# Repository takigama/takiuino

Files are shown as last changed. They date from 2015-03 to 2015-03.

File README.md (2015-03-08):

# Takiuino - the arduino compatible board for ME!

Just a WIP atm, look in the eagle directory and you can see the boards and their OSHPark links, though v2.0 has now
been tested against both arduino v1.0.x and arduino v1.5.7 and v1.6.0.

The main site for the takiuino is here: http://pjr.cc/tu/ (which is comming soon)

## Thanks go to....

Maniacbug - for his work on the 1284 originally, from [here](https://maniacbug.wordpress.com/2011/11/27/arduino-on-atmega1284p-4/).

The Optiboot folk - for making the awesome optiboot code! Available [here](https://code.google.com/p/optiboot/).

## What is it?

A fork of Maniacbug's mighty1284 code base, also includes the 644p code.

I've removed everything except the optiboot options (for now)

## What do you need?

First you need the board, which is on oshpark [here](https://oshpark.com/shared_projects/BunCIt50) for V3.1 or
[here](https://oshpark.com/shared_projects/wfCfnxof) for V3.2. The only difference between them is how the ICSP and reset swtiches are layed out.

# V3.1
Top
Bottom

# V3.2
Top
Bottom
Then you need to make the board (its pretty simple)

1. decide what you need, if your powering from a stable 5v source, you dont need the 5v REG (though keeping the 5v cap, C1, isnt a bad idea)
If you dont need a 3.3v line, you can drop the 3.3v REG as well (and its capacitor, C2).

2. the polarized components (2 caps, 2 leds) have their positive lines marked

3. Conquer the world. They'll be a better written tutorial coming soon, as well as an annotated
image of the actual board and components that go on it. But for the impatient the components are as follows:

- C1, C2: 10uf Tant CAP (16v rated)
- RES: SMD resontator (16mhz), Murata CSTCE16M0V53-R0 is appropriate
- C4: 0.1uf (100nf) 0603 sized ceramic cap
- R1: 330 ohm 0603 sized resister
- R2: 220 ohm 0603 sized resister (can also be 330 ohm if you wish)
- S1: SMD push button switch
- L2, L3: 0603 sized SMD led (note polarity)
- 1117-5v: AMS/LM1117 5v regulator
- 1117-3.3v: AMS/LM1117 3.3v regulator
- ATmega: ATmega1284p-au or ATmega644p-au (which ever suits you) should be a little circle on the chip, which 
goes with the printed circle on the board

Personally i find the resonator the hardest bit to solder, but doesnt take too much to long to get the hang
of it. After that, hook up an ASP and go program it directly with code, or use a bootloader and program via
the serial pinouts (note you'll need a USB to uart thingo).

If it all works, L3 should come on when power to the board is applied and you can control L2 via pummelling
pin 23 (which is what L2 is connected to). The following code should work:

```
int ledPin = 23;                 // LED connected to digital pin 23
float tLat = 1024;
bool dirUp = true;

void setup()
{
  Serial.begin(115200);
  pinMode(ledPin, OUTPUT);      // sets the digital pin as output
}

void loop()
{

  digitalWrite(ledPin, HIGH);   // sets the LED on
  delay(tLat);                  // waits for a bit
  digitalWrite(LED, LOW);       // sets the LED off
  // note that i use "LED" above, which is defined
  // in the hardware library for this pin
  delay(tLat);                  // waits for a bit

  if(tLat > 1024) {
    Serial.println("Switch direction, down");
    dirUp = false;

  }

  if(tLat < 2) {
    Serial.println("Switch direction, up");
    dirUp = true;
  }

  if(dirUp) {
    tLat = tLat*1.2;
  } else {
    tLat = tLat/1.2;
  }

  Serial.print("tlat now: ");
  Serial.println(tLat);

}

```
This should cause the L2 led to start as a slow on/off then ramp up and eventually stay on, then reset and start again.

## Installation

copy the contents of the arduino-ide folder into you arduino ide's hardware directory

## Why?

Originally started as a project to create something very specific, hence why the original V1 board has a
MOSFET on the board.

Second reason was cause I could, always wanted to design my own board for a microctronoller and this worked
out well.

Third was that I wanted a board with more useful pinout info, not many of the smaller boards have any markings
to tell you which channel is a pwm line, etc. The code also allow you to call pins via the names on
either side of the board (hence whey they're both there).

Lastly, I needed something small (round the pro mini/micro size) with two serial ports, the ability to run
an OLED screen (which requires quite some memory) along with some other memory sapping parts

## TODO

- I think I may regret the position of the reset switch as its sitting very close to the resonator (i'll know once
the v3 prints arrive from OSH Park)
- Write a test harness and some programs to check that the pins all work

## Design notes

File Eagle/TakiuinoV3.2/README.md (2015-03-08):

# Takuino V3.2 - the final countdown, part 2

Flipped the ICSP header around, moved reset switch as it was a bit close to the resonator

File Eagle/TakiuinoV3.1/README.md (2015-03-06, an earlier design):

# Takuino V3.1 - the final countdown

Not quite here yet cause im a bit lazy sometimes.

Basically takiuino V3 will be V2 with the following additinos:
- silk screens on both sides with pin layouts
- ISCP Header holes
- Reset Button pads

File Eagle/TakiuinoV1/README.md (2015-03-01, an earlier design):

# Takiuino V1

This board had a very specific purpose and should never actually be built, unless you very much want a board with an inbuilt MOSFET connector.

I've included the gerber files, or alternatively it can be printed on oshpark https://oshpark.com/shared_projects/UIUpYUVF

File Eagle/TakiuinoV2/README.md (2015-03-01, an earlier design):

# Takuino V2

After making Takiuino V1, someone saw it and asked if they could have a generic version of it with all the pins exposed and without the mosfet driver. So here it is.

Also available on OSHPark: https://oshpark.com/shared_projects/RhMgGB3u

This board works quite well, though V3 which is just around the corner will be a bit of an improvement and best to hold off for that if you can

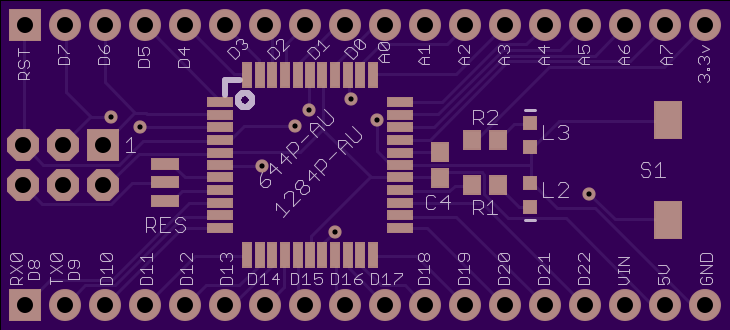
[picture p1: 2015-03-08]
Eagle/TakiuinoV3.2/oshpark-renders/top.png

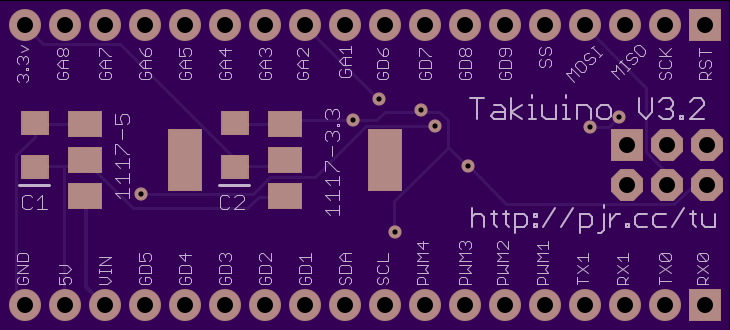
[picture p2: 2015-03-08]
Eagle/TakiuinoV3.2/oshpark-renders/bottom.png

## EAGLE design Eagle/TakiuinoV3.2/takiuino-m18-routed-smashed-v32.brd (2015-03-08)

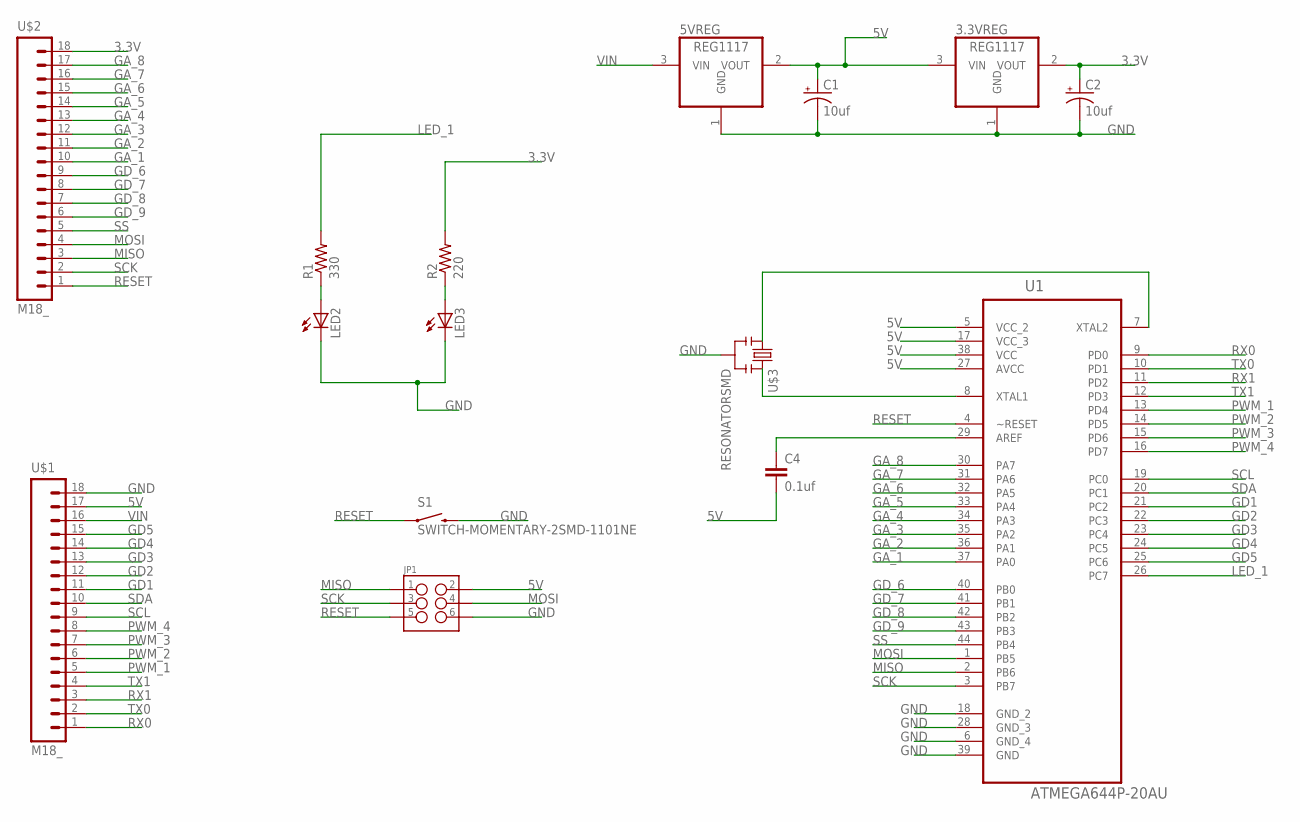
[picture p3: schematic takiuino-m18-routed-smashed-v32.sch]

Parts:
3.3VREG, 5VREG: REG1117; SOT223
C1, C2: 10uf; EIA3216
C4: 0.1uf; 0603-CAP
JP1: M03X2NO_SILK; 2X3-NS
LED2, LED3: LEDCHIP-LED0603; CHIP-LED0603
R1: 330; R0603
R2: 220; R0603
S1: SWITCH-MOMENTARY-2SMD-1101NE; TACTILE-SWITCH-1101NE
U1: ATMEGA644P-20AU; QFP80P1200X1200X120-44N
U$1, U$2: M18_; 1X18
U$3: RESONATORSMD; RESONATOR-SMD

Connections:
3.3V: 3.3VREG.2 (VOUT), C2.A (+), R2.2, U$2.18
5V: 3.3VREG.3 (VIN), 5VREG.2 (VOUT), C1.A (+), C4.2, JP1.2, U1.5 (VCC_2), U1.17 (VCC_3), U1.27 (AVCC), U1.38 (VCC), U$1.17
GA_1: U1.37 (PA0), U$2.10
GA_2: U1.36 (PA1), U$2.11
GA_3: U1.35 (PA2), U$2.12
GA_4: U1.34 (PA3), U$2.13
GA_5: U1.33 (PA4), U$2.14
GA_6: U1.32 (PA5), U$2.15
GA_7: U1.31 (PA6), U$2.16
GA_8: U1.30 (PA7), U$2.17
GD1: U1.21 (PC2), U$1.11
GD2: U1.22 (PC3), U$1.12
GD3: U1.23 (PC4), U$1.13
GD4: U1.24 (PC5), U$1.14
GD5: U1.25 (PC6), U$1.15
GD_6: U1.40 (PB0), U$2.9
GD_7: U1.41 (PB1), U$2.8
GD_8: U1.42 (PB2), U$2.7
GD_9: U1.43 (PB3), U$2.6
GND: 3.3VREG.1 (GND), 5VREG.1 (GND), C1.C (-), C2.C (-), JP1.6, LED2.C, LED3.C, S1.2, U1.6 (GND_4), U1.18 (GND_2), U1.28 (GND_3), U1.39 (GND), U$1.18, U$3.2
LED_1: R1.2, U1.26 (PC7)
MISO: JP1.1, U1.2 (PB6), U$2.3
MOSI: JP1.4, U1.1 (PB5), U$2.4
unnamed: U1.8 (XTAL1), U$3.3
unnamed: U1.7 (XTAL2), U$3.1
unnamed: C4.1, U1.29 (AREF)
unnamed: LED2.A, R1.1
unnamed: LED3.A, R2.1
PWM_1: U1.13 (PD4), U$1.5
PWM_2: U1.14 (PD5), U$1.6
PWM_3: U1.15 (PD6), U$1.7
PWM_4: U1.16 (PD7), U$1.8
RESET: JP1.5, S1.1, U1.4 (~RESET), U$2.1
RX0: U1.9 (PD0), U$1.1
RX1: U1.11 (PD2), U$1.3
SCK: JP1.3, U1.3 (PB7), U$2.2
SCL: U1.19 (PC0), U$1.9
SDA: U1.20 (PC1), U$1.10
SS: U1.44 (PB4), U$2.5
TX0: U1.10 (PD1), U$1.2
TX1: U1.12 (PD3), U$1.4
VIN: 5VREG.3 (VIN), U$1.16

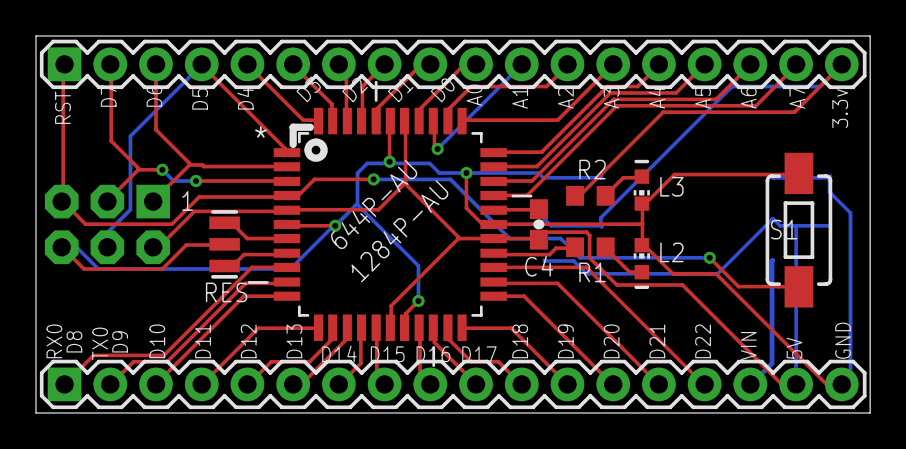
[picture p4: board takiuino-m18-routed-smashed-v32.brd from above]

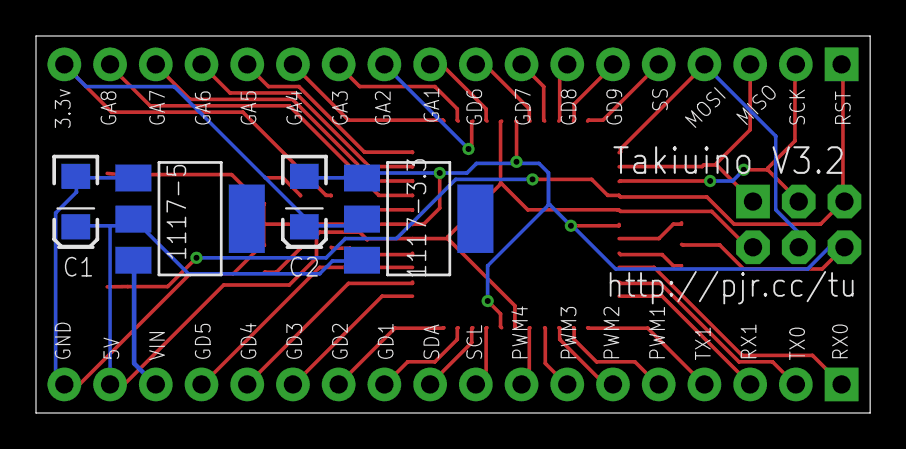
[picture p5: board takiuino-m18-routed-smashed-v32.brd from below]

Board: 2 copper layers, 46.3 x 20.9 mm, 15 parts (4 on the bottom side), 42 nets.

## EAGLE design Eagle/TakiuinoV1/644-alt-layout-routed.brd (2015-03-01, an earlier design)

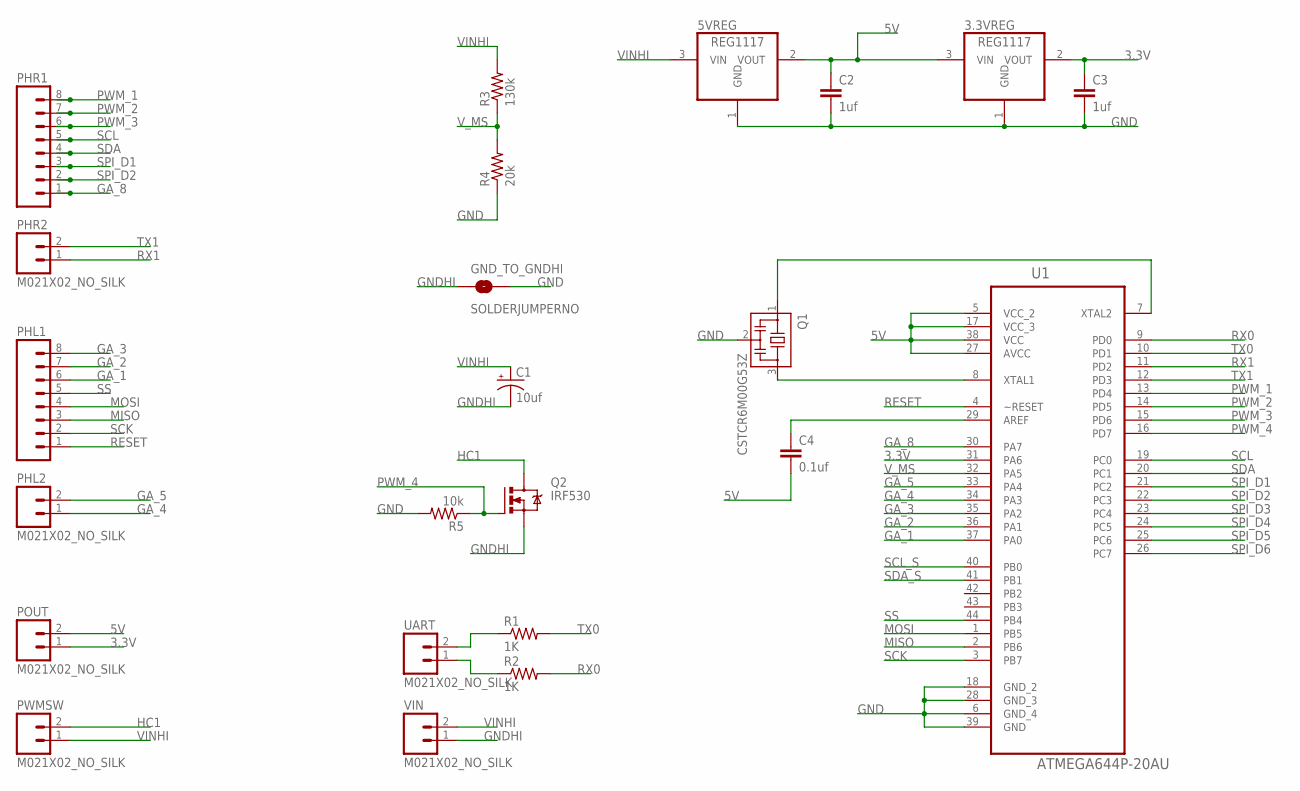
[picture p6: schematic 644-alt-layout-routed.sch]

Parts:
3.3VREG, 5VREG: REG1117; SOT223
C1: 10uf; EIA3216
C2, C3: 1uf; 0603-CAP
C4: 0.1uf; 0603-CAP
GND_TO_GNDHI: SOLDERJUMPERNO; SJ_2S-NO
PHL1: M08NO_SILK; 1X08_PIN1_NO_SILK
PHL2: M021X02_NO_SILK; 1X02_NO_SILK
PHR1: M08NO_SILK; 1X08_PIN1_NO_SILK
PHR2: M021X02_NO_SILK; 1X02_NO_SILK
POUT: M021X02_NO_SILK; 1X02_NO_SILK
PWMSW: M021X02_NO_SILK; 1X02_NO_SILK
Q1: CSTCR6M00G53Z; CSTCR6M
Q2: IRF530; TO220BV
R1, R2: 1K; 0603-RES
R3: 130k; 0603-RES
R4: 20k; 0603-RES
R5: 10k; 0603-RES
U1: ATMEGA644P-20AU; QFP80P1200X1200X120-44N
UART: M021X02_NO_SILK; 1X02_NO_SILK
VIN: M021X02_NO_SILK; 1X02_NO_SILK

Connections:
3.3V: 3.3VREG.2 (VOUT), C3.1, POUT.1, U1.31 (PA6)
5V: 3.3VREG.3 (VIN), 5VREG.2 (VOUT), C2.1, C4.2, POUT.2, U1.5 (VCC_2), U1.17 (VCC_3), U1.27 (AVCC), U1.38 (VCC)
GA_1: PHL1.6, U1.37 (PA0)
GA_2: PHL1.7, U1.36 (PA1)
GA_3: PHL1.8, U1.35 (PA2)
GA_4: PHL2.1, U1.34 (PA3)
GA_5: PHL2.2, U1.33 (PA4)
GA_8: PHR1.1, U1.30 (PA7)
GND: 3.3VREG.1 (GND), 5VREG.1 (GND), C2.2, C3.2, GND_TO_GNDHI.2, Q1.2, R4.1, R5.2, U1.6 (GND_4), U1.18 (GND_2), U1.28 (GND_3), U1.39 (GND)
GNDHI: C1.C (-), GND_TO_GNDHI.1, Q2.S, VIN.1
HC1: PWMSW.2, Q2.D
MISO: PHL1.3, U1.2 (PB6)
MOSI: PHL1.4, U1.1 (PB5)
unnamed: Q1.3, U1.8 (XTAL1)
unnamed: Q1.1, U1.7 (XTAL2)
unnamed: C4.1, U1.29 (AREF)
unnamed: R1.1, UART.2
unnamed: R2.1, UART.1
PWM_1: PHR1.8, U1.13 (PD4)
PWM_2: PHR1.7, U1.14 (PD5)
PWM_3: PHR1.6, U1.15 (PD6)
PWM_4: Q2.G, R5.1, U1.16 (PD7)
RESET: PHL1.1, U1.4 (~RESET)
RX0: R2.2, U1.9 (PD0)
RX1: PHR2.1, U1.11 (PD2)
SCK: PHL1.2, U1.3 (PB7)
SCL: PHR1.5, U1.19 (PC0)
SCL_S: U1.40 (PB0)
SDA: PHR1.4, U1.20 (PC1)
SDA_S: U1.41 (PB1)
SPI_D1: PHR1.3, U1.21 (PC2)
SPI_D2: PHR1.2, U1.22 (PC3)
SPI_D3: U1.23 (PC4)
SPI_D4: U1.24 (PC5)
SPI_D5: U1.25 (PC6)
SPI_D6: U1.26 (PC7)
SS: PHL1.5, U1.44 (PB4)
TX0: R1.2, U1.10 (PD1)
TX1: PHR2.2, U1.12 (PD3)
VINHI: 5VREG.3 (VIN), C1.A (+), PWMSW.1, R3.2, VIN.2
V_MS: R3.1, R4.2, U1.32 (PA5)

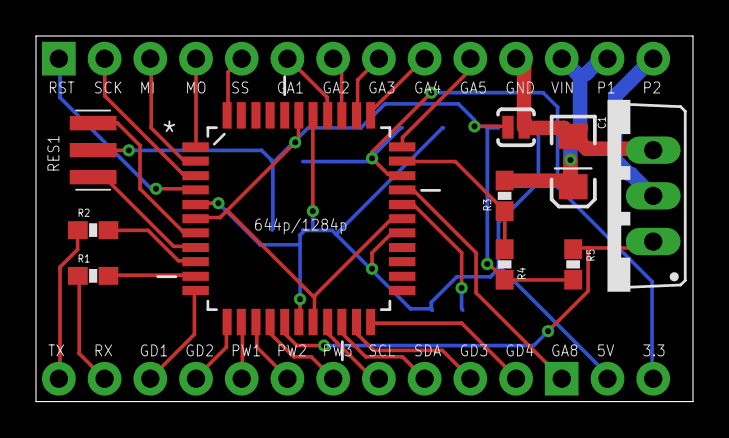
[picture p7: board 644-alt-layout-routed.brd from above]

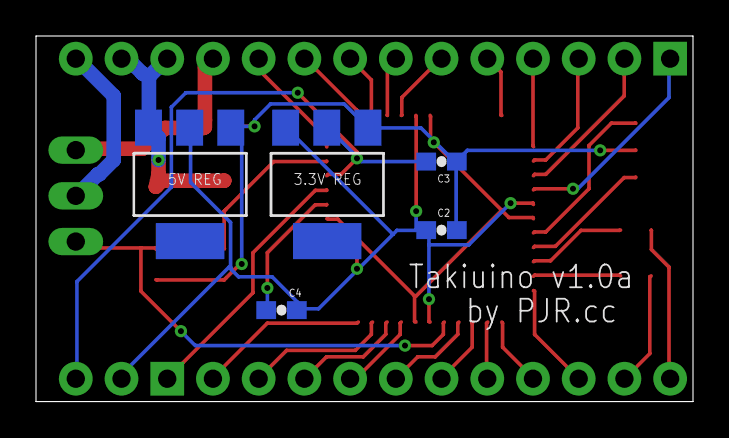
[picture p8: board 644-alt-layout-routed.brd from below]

Board: 2 copper layers, 36.5 x 20.3 mm, 23 parts (5 on the bottom side), 35 nets.

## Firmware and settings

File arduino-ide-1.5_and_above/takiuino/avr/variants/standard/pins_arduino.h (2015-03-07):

#ifndef Pins_Arduino_h
#define Pins_Arduino_h

#include <avr/pgmspace.h>

// ATMEL ATMEGA1284P
//
//                   +---\/---+
//           (D 0) PB0  1|        |40  PA0 (AI 0 / D24)
//           (D 1) PB1  2|        |39  PA1 (AI 1 / D25)
//      INT2 (D 2) PB2  3|        |38  PA2 (AI 2 / D26)
//       PWM (D 3) PB3  4|        |37  PA3 (AI 3 / D27)
//    PWM/SS (D 4) PB4  5|        |36  PA4 (AI 4 / D28)
//      MOSI (D 5) PB5  6|        |35  PA5 (AI 5 / D29)
//  PWM/MISO (D 6) PB6  7|        |34  PA6 (AI 6 / D30)
//   PWM/SCK (D 7) PB7  8|        |33  PA7 (AI 7 / D31)
//                 RST  9|        |32  AREF
//                 VCC 10|        |31  GND 
//                 GND 11|        |30  AVCC
//               XTAL2 12|        |29  PC7 (D 23)
//               XTAL1 13|        |28  PC6 (D 22)
//      RX0 (D 8)  PD0 14|        |27  PC5 (D 21) TDI
//      TX0 (D 9)  PD1 15|        |26  PC4 (D 20) TDO
// RX1/INT0 (D 10) PD2 16|        |25  PC3 (D 19) TMS
// TX1/INT1 (D 11) PD3 17|        |24  PC2 (D 18) TCK
//      PWM (D 12) PD4 18|        |23  PC1 (D 17) SDA
//      PWM (D 13) PD5 19|        |22  PC0 (D 16) SCL
//      PWM (D 14) PD6 20|        |21  PD7 (D 15) PWM
//                   +--------+
//

/*
   PCINT15-8: D7-0  : bit 1
   PCINT31-24: D15-8  : bit 3
   PCINT23-16: D23-16 : bit 2
   PCINT7-0: D31-24   : bit 0
   */

#define NUM_DIGITAL_PINS            31
#define NUM_ANALOG_INPUTS           8
#define analogInputToDigitalPin(p)  ((p < NUM_ANALOG_INPUTS) ? (p) + 24 : -1)

#define digitalPinHasPWM(p)         ((p) == 3 || (p) == 4 || (p) == 6 || (p) == 7 || (p) == 12 || (p) == 13 || (p) == 14 || (p) == 15)


// backside pin def's
static const uint8_t PWM1 = 12;
static const uint8_t PWM2 = 13;
static const uint8_t PWM3 = 14;
static const uint8_t PWM4 = 15;

// second serial port
static const uint8_t RX1 = 10;
static const uint8_t TX1 = 11;

// on board led which i didnt bring to a pin
static const uint8_t LED = 23;
static const uint8_t LED1 = 23;

// general analog ports
static const uint8_t GA1 = 24;
static const uint8_t GA2 = 25;
static const uint8_t GA3 = 26;
static const uint8_t GA4 = 27;
static const uint8_t GA5 = 28;
static const uint8_t GA6 = 29;
static const uint8_t GA7 = 30;
static const uint8_t GA8 = 31;

// general digital ports
static const uint8_t GD1 = 18;
static const uint8_t GD2 = 19;
static const uint8_t GD3 = 20;
static const uint8_t GD4 = 21;
static const uint8_t GD5 = 22;
static const uint8_t GD6 = 0;
static const uint8_t GD7 = 1;
static const uint8_t GD8 = 2;
static const uint8_t GD9 = 3;

// end backside pin defs


static const uint8_t SS   = 4;
static const uint8_t MOSI = 5;
static const uint8_t MISO = 6;
static const uint8_t SCK  = 7;

static const uint8_t SDA = 17;
static const uint8_t SCL = 16;

static const uint8_t A0 = 24;
static const uint8_t A1 = 25;
static const uint8_t A2 = 26;
static const uint8_t A3 = 27;
static const uint8_t A4 = 28;
static const uint8_t A5 = 29;
static const uint8_t A6 = 30;
static const uint8_t A7 = 31;

#define digitalPinToPCICR(p)    (((p) >= 0 && (p) < NUM_DIGITAL_PINS) ? (&PCICR) : ((uint8_t *)0))
#define digitalPinToPCICRbit(p) (((p) <= 7) ? 1 : (((p) <= 15) ? 3 : (((p) <= 23) ? 2 : 0)))
#define digitalPinToPCMSK(p)    (((p) <= 7) ? (&PCMSK2) : (((p) <= 13) ? (&PCMSK0) : (((p) <= 21) ? (&PCMSK1) : ((uint8_t *)0))))
#define digitalPinToPCMSKbit(p) ((p) % 8)

#ifdef ARDUINO_MAIN

#define PA 1
#define PB 2
#define PC 3
#define PD 4

// these arrays map port names (e.g. port B) to the
// appropriate addresses for various functions (e.g. reading
// and writing)
const uint16_t PROGMEM port_to_mode_PGM[] =
{
	NOT_A_PORT,
	(uint16_t) &DDRA,
	(uint16_t) &DDRB,
	(uint16_t) &DDRC,
	(uint16_t) &DDRD,
};

const uint16_t PROGMEM port_to_output_PGM[] =
{
	NOT_A_PORT,
	(uint16_t) &PORTA,
	(uint16_t) &PORTB,
	(uint16_t) &PORTC,
	(uint16_t) &PORTD,
};

const uint16_t PROGMEM port_to_input_PGM[] =
{
	NOT_A_PORT,
	(uint16_t) &PINA,
	(uint16_t) &PINB,
	(uint16_t) &PINC,
	(uint16_t) &PIND,
};

const uint8_t PROGMEM digital_pin_to_port_PGM[] =
{
	PB, /* 0 */
	PB,
	PB,
	PB,
	PB,
	PB,
	PB,
	PB,
	PD, /* 8 */
	PD,
	PD,
	PD,
	PD,
	PD,
	PD,
	PD,
	PC, /* 16 */
	PC,
	PC,
	PC,
	PC,
	PC,
   	PC,
	PC,
	PA, /* 24 */
	PA,
	PA,
	PA,
	PA,
	PA,
	PA,
	PA  /* 31 */
};

const uint8_t PROGMEM digital_pin_to_bit_mask_PGM[] =
{
	_BV(0), /* 0, port B */
	_BV(1),
	_BV(2),
	_BV(3),
	_BV(4),
	_BV(5),
	_BV(6),
	_BV(7),
	_BV(0), /* 8, port D */
	_BV(1),
	_BV(2),
	_BV(3),
	_BV(4),
	_BV(5),
	_BV(6),
	_BV(7),
	_BV(0), /* 16, port C */
	_BV(1),
	_BV(2),
	_BV(3),
	_BV(4),
	_BV(5),
	_BV(6),
	_BV(7),
	_BV(0), /* 24, port A */
	_BV(1),
	_BV(2),
	_BV(3),
	_BV(4),
	_BV(5),
	_BV(6),
	_BV(7)
};
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

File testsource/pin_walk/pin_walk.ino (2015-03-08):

/*

This sketch should cause each pin to be switched on for about 50ms, and walks everypin

*/

int walking[] = {RX1, TX1, PWM1, PWM2, PWM3, PWM4, SCL, SDA, GD1, GD2, GD3, GD4, GD5, GA8, GA7, GA6, GA5, GA4, GA3, GA2, GA1, GD6, GD7, GD8, GD9, SS, MOSI, MISO, SCK};
int tLat = 100;

void setup()
{
  Serial.begin(115200);

  pinMode(LED, OUTPUT);
  for(int i=0; i<28; i++) {
    pinMode(i, OUTPUT);      // sets the digital pin as output
  }
}

void loop()
{
  
  int lpin=0;
  bool ledPin = false;
  
  
  for(int i=0; i<28; i++) {
    Serial.print("punching pin: ");
    Serial.println(walking[i]);
    
    if(ledPin) {
      ledPin = false;
      digitalWrite(LED, HIGH);
    } else {
      ledPin = true;
      digitalWrite(LED, LOW);
    }
    digitalWrite(lpin, LOW);
    digitalWrite(walking[i], HIGH);
    lpin = i;
    delay(tLat);
  }
}

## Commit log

2015-03-01 initial project drop into github
    [pins.ods]
2015-03-05 Takuino V3 eagle files
    [op_takiuino-m18-routed-smashed.gbl, op_takiuino-m18-routed-smashed.gbo, op_takiuino-m18-routed-smashed.gbs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]
2015-03-06 Updates for the takiuino v3.1 board - pin number fixed and positive terminals marked on polarised componets
    [op_takiuino-m18-routed-smashed.gbl, op_takiuino-m18-routed-smashed.gbo, op_takiuino-m18-routed-smashed.gbs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]
2015-03-06 updated for small layout fixes, make markings a little easier to read
    [takiuino-m18-routed-smashed.brd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]
2015-03-06 ocd kicked in and one of the lines was slightly out - was driving me nuts - updated
    [takiuino-m18-routed-smashed.brd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]
2015-03-07 pin definitions for backside port names (on the silk screen) defined
2015-03-08 changes for arduino 1.5
2015-03-08 tested and working with arduino 1.0 and 1.5/1.6
2015-03-08 slight change to the way the accelarating led code works (now bounces)
2015-03-08 Update for v3.2 with moved ICSP and switch
    [op_takiuino-m18-routed-smashed-v32.gbl, op_takiuino-m18-routed-smashed-v32.gbo, op_takiuino-m18-routed-smashed-v32.gbs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]

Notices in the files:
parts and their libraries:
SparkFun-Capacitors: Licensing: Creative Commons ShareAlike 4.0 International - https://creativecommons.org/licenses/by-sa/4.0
